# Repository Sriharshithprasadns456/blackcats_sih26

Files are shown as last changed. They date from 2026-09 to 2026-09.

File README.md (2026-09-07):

# BLACKCATS_SIH26
This Smart India Hackathon 2026 presentation by Team BLACKCATS details HI-CAS (Helmet-Integrated Conformal Antenna System).
# 🐈‍⬛ BLACKCATS — HI-CAS

### Helmet-Integrated Conformal Antenna System for Tactical Communications

> **ONE TEAM. ONE LINK. ZERO COMMUNICATION GAPS.**






---

## 📌 About the Project

**HI-CAS (Helmet-Integrated Conformal Antenna System)** is a compact, low-profile antenna architecture designed for **tactical communication in confined urban environments and Close-Quarter Battle (CQB) operations**.

The system replaces conventional protruding whip antennas with **helmet-integrated conformal antenna arrays**, reducing exposed hardware while maintaining reliable RF communication.

The proposed architecture uses **two independent single-band conformal antenna arrays**, supporting **UHF and L-band communication**, with a **diplexer** providing a single RF interface and **phase control** for improved signal coverage.

---

## 🎯 Problem Statement

### SIH 2026 — Problem Statement ID: 26185

**Helmet mounted conformal antenna for tactical communications in urban CQB environments.**

Traditional radio antennas create several challenges in confined environments:

* 📡 Protruding antennas can snag on surroundings.
* 🪖 Rigid antennas do not conform to helmet geometry.
* 📶 Helmet curvature and head proximity affect RF performance.
* 🔄 A compact platform must support multiple communication bands.
* ⚙️ Antenna performance can vary under realistic operating conditions.

---

## 💡 Our Solution

HI-CAS integrates the antenna directly with the helmet surface while maintaining a compact and modular architecture.

### Key Features

| Feature | Description |
| --- | --- |
| 🪖 **Conformal** | Follows the curvature of the helmet |
| 📡 **Dual-Band Architecture** | Separate optimized arrays for UHF and L-band |
| 📏 **Low Profile** | Minimizes exposed hardware and snag risk |
| 🔌 **Single RF Interface** | UHF and L-band are combined through a diplexer |
| 🎛️ **Phase Control** | Optimizes radiation coverage |
| 🔧 **Retrofittable** | Designed for compatibility with existing helmet systems |
| 🧩 **Modular** | Architecture can be adapted to different helmet/radio platforms |

---

## 🏗️ System Architecture

```text
                 ┌─────────────────────┐
                 │     HELMET SHELL    │
                 └──────────┬──────────┘
                            │
             ┌──────────────┴──────────────┐
             │                             │
     ┌───────▼────────┐           ┌────────▼───────┐
     │  UHF CONFORMAL │           │ L-BAND         │
     │     ARRAY      │           │ CONFORMAL ARRAY│
     └───────┬────────┘           └────────┬───────┘
             │                             │
             └──────────────┬──────────────┘
                            │
                      ┌─────▼─────┐
                      │  DIPLEXER │
                      └─────┬─────┘
                            │
                      ┌─────▼─────┐
                      │ PHASE     │
                      │ CONTROL   │
                      └─────┬─────┘
                            │
                      ┌─────▼─────┐
                      │ SINGLE RF │
                      │ INTERFACE │
                      └───────────┘
```

### Operating Bands

* **UHF:** 200–450 MHz
* **L-band:** 1.2–1.5 GHz

The architecture combines the two independently optimized antenna paths into a **single tactical RF interface**.

---

## 🔬 Engineering Approach

The project focuses on integrating existing RF technologies into a helmet-compatible platform and validating their performance under realistic operating conditions.

### Development Flow

```text
DESIGN
   ↓
SIMULATE
   ↓
PROTOTYPE
   ↓
BEND TEST
   ↓
TEMPERATURE TEST
   ↓
RF VALIDATION
   ↓
STRUCTURAL VALIDATION
```

The main engineering challenges include:

### 1. Helmet Curvature

Bending can alter electrical length and electromagnetic coupling.

**Parameters to evaluate:**

* Resonant frequency
* S11
* VSWR
* Bandwidth

### 2. Temperature

Environmental temperature variations can influence antenna materials and RF behaviour.

**Validation:**

* RF measurements before temperature cycling
* RF measurements after temperature cycling

### 3. Head Proximity

The operator's head changes the electromagnetic environment surrounding the antenna.

**Parameters:**

* Impedance
* Efficiency
* Radiation characteristics

### 4. Structural Integration

The antenna must integrate with the helmet without compromising its intended functionality or protection.

Structural/ballistic certification is **not claimed** by this project and would require dedicated validation.

---

## 🧪 Validation

The prototype will be evaluated through:

* Antenna simulation
* S-parameter measurements
* VSWR measurements
* Bandwidth characterization
* Curvature/bending tests
* Temperature testing
* Head-proximity testing
* Radiation-pattern evaluation
* Efficiency measurements
* Structural integration assessment

---

## 🚀 Expected Impact

### Operational

Reduced physical obstruction and improved operator mobility in confined environments.

### RF Performance

Independent band-optimized conformal arrays provide a flexible approach to multi-band tactical communication.

### User Safety

Reduced exposed antenna components can reduce potential snag points.

### Scalability

The modular UHF/L-band architecture can potentially be adapted to different helmet and radio platforms.

### Potential Applications

* NSG / ATS teams
* Specialized tactical units
* Helmet-based communication systems
* Other applications requiring compact integrated RF systems

All applications remain subject to appropriate technical validation, certification and procurement requirements.

---

## 🛠️ Technologies & Tools

### RF / Antenna

* Conformal antenna arrays
* UHF antenna design
* L-band antenna design
* Diplexer
* Phase-control network
* RF measurement and characterization

### Simulation & Design

The project can be developed and validated using electromagnetic simulation and RF design tools.

### Hardware

* Helmet-integrated antenna prototype
* RF interconnects
* Diplexer
* Phase-control circuitry
* Tactical-radio interface

---

## 📂 Repository Structure

```text
blackcats_sih26/
│
├── README.md
│
├── antenna-design/
│   ├── UHF/
│   └── L-band/
│
├── simulations/
│   ├── radiation-patterns/
│   ├── S11/
│   ├── VSWR/
│   └── bandwidth/
│
├── hardware/
│   ├── schematics/
│   ├── PCB/
│   └── prototype/
│
├── mechanical/
│   ├── helmet-CAD/
│   └── mounting/
│
├── results/
│   ├── measurements/
│   └── plots/
│
├── documentation/
│
└── LICENSE
```

---

## 👥 Team

### BLACKCATS

**Smart India Hackathon 2026**

**Team ID:** 007
**Problem Statement:** 26185
**Category:** Hardware
**Theme:** Robotics and Drones

---

## 📜 Project Status

🚧 **Prototype / Development Stage**

The project is currently focused on antenna design, simulation, prototype development and validation.

The core technologies required for the system exist; the primary engineering challenge is their **integration and validation under realistic operating conditions**.

---

## 📚 References

Project documentation and research material will be maintained in this repository.

**Official repository:**
https://github.com/Sriharshithprasadns456/blackcats_sih26

---

## ⚠️ Disclaimer

This project is a **research and engineering prototype** developed for Smart India Hackathon 2026.

Performance, structural integrity, ballistic protection and operational suitability must be independently validated before any real-world deployment.

---

<p align="center">

### 🐈‍⬛ BLACKCATS

**ONE TEAM. ONE LINK. ZERO COMMUNICATION GAPS.**

</p>

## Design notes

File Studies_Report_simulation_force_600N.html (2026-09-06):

- Header
- Report Properties
- Simulation Model 1
  - Study 1 - Static Stress
    - Study Properties
    - Study Setup
      - Settings
      - Materials
      - Contacts
      - Mesh
      - Load Case1
        - Constraints
        - Loads
        - Guided Results
          - Safety Factor
        - Results
          - Result Summary
          - Safety Factor
          - Stress
          - Displacement

Study Report

Analyzed File | helmet | Version | Autodesk Fusion (2704.1.53)
Creation Date | 2026-09-06, 05:58:10 | Author | HP

Report Properties

Report Properties
Title | Studies
Author | HP

Simulation Model 1

Study 1 - Static Stress

Study Properties

Study Properties
Study Type | Static Stress
Last Modification Date | 2026-09-06, 05:12:41

Study Setup

Settings
General

Contact Tolerance | 0.10 mm
Remove Rigid Body Modes | No
Mesh

Average Element Size (% of model size) - Solids | 10
Scale Mesh Size Per Part | No
Average Element Size (absolute value) | -
Element Order | Parabolic
Create Curved Mesh Elements | Yes
Max. Turn Angle on Curves (Deg.) | 60
Max. Adjacent Mesh Size Ratio | 1.5
Max. Aspect Ratio | 10
Minimum Element Size (% of average size) | 20
Adaptive Mesh Refinement

Number of Refinement Steps | 0
Results Convergence Tolerance (%) | 20
Portion of Elements to Refine (%) | 10
Results for Baseline Accuracy | von Mises Stress

Materials
Nylon 6/6(2)
Components

Component | Strength
Body3 | Yield Strength
Properties

Density | 1.420E-06 kg / mm^3
Young's Modulus | 2500.00 MPa
Poisson's Ratio | 0.34
Yield Strength | 69.00 MPa
Ultimate Tensile Strength | 231.00 MPa
Thermal Conductivity | 1.200E-04 W / (mm C)
Thermal Expansion Coefficient | 2.000E-05 / C
Specific Heat | 1090.00 J / (kg C)
Nylon 6/6(1)
Components

Component | Strength
Body5 | Yield Strength
Properties

Density | 2.202E-06 kg / mm^3
Young's Modulus | 3712.00 MPa
Poisson's Ratio | 0.17
Yield Strength | 138.00 MPa
Ultimate Tensile Strength | 69.00 MPa
Thermal Conductivity | 2.000E-04 W / (mm C)
Thermal Expansion Coefficient | 4.000E-05 / C
Specific Heat | 960.00 J / (kg C)
TPU(1)
Components

Component | Strength
Body7 | Yield Strength
Properties

Density | 2.240E-06 kg / mm^3
Young's Modulus | 1500.00 MPa
Poisson's Ratio | 0.40
Yield Strength | 19.00 MPa
Ultimate Tensile Strength | 19.00 MPa
Thermal Conductivity | 4.300E-04 W / (mm C)
Thermal Expansion Coefficient | 1.200E-04 / C
Specific Heat | 950.00 J / (kg C)
Nylon 6/6(3)
Components

Component | Strength
Body2 | Yield Strength
Properties

Density | 4.800E-06 kg / mm^3
Young's Modulus | 120000.00 MPa
Poisson's Ratio | 0.28
Yield Strength | 45.00 MPa
Ultimate Tensile Strength | 45.00 MPa
Thermal Conductivity | 0.004 W / (mm C)
Thermal Expansion Coefficient | 9.000E-06 / C
Specific Heat | 750.00 J / (kg C)
Nylon 6/6(4)
Components

Component | Strength
Body1 | Yield Strength
Body10 | Yield Strength
Body11 | Yield Strength
Body12 | Yield Strength
Body13 | Yield Strength
Body14 | Yield Strength
Body8 | Yield Strength
Body9 | Yield Strength
Properties

Density | 1.440E-06 kg / mm^3
Young's Modulus | 70300.00 MPa
Poisson's Ratio | 0.36
Yield Strength | 2920.00 MPa
Ultimate Tensile Strength | 3620.00 MPa
Thermal Conductivity | 4.000E-05 W / (mm C)
Thermal Expansion Coefficient | 1.000E-07 / C
Specific Heat | 1420.00 J / (kg C)
Copper
Components

Component | Strength
Body4 | Yield Strength
Body6 | Yield Strength
Properties

Density | 8.940E-06 kg / mm^3
Young's Modulus | 117500.00 MPa
Poisson's Ratio | 0.345
Yield Strength | 33.30 MPa
Ultimate Tensile Strength | 210.00 MPa
Thermal Conductivity | 0.401 W / (mm C)
Thermal Expansion Coefficient | 1.670E-05 / C
Specific Heat | 450.00 J / (kg C)

Contacts
Contact Type | Contact Set | Penetration Type | Bodies | Entities
Bonded

Bonded1 | Symmetric | [Body13||Body14] | [Face 1066||Face 1088]
Bonded2 | Symmetric | [Body12||Body14] | [Face 1045||Face 1088]
Bonded3 | Symmetric | [Body12||Body13] | [Face 1045||Face 1067]
Bonded4 | Symmetric | [Body11||Body12] | [Face 1024||Face 1046]
Bonded5 | Symmetric | [Body10||Body11] | [Face 1004||Face 1024]
Bonded6 | Symmetric | [Body10||Body12] | [Face 1003||Face 1046]
Bonded7 | Symmetric | [Body10||Body11] | [Face 1003||Face 1025]
Bonded8 | Symmetric | [Body9||Body12] | [Face 982||Face 1046]
Bonded9 | Symmetric | [Body9||Body11] | [Face 982||Face 1025]
Bonded10 | Symmetric | [Body9||Body10] | [Face 982||Face 1004]
Bonded11 | Symmetric | [Body8||Body9] | [Face 961||Face 983]
Bonded12 | Symmetric | [Body7||Body14] | [Face 945||Face 1089]
Bonded13 | Symmetric | [Body7||Body14] | [Face 944||Face 1092]
Bonded14 | Symmetric | [Body7||Body14] | [Face 943||Face 1091]
Bonded15 | Symmetric | [Body7||Body14] | [Face 942||Face 1090]
Bonded16 | Symmetric | [Body6||Body7] | [Face 929||Face 946]
Bonded17 | Symmetric | [Body6||Body12] | [Face 925||Face 1049]
Bonded18 | Symmetric | [Body5||Body13] | [Face 911||Face 1067]
Bonded19 | Symmetric | [Body5||Body7] | [Face 911||Face 946]
Bonded20 | Symmetric | [Body5||Body6] | [Face 911||Face 928]
Bonded21 | Symmetric | [Body5||Body12] | [Face 909||Face 1047]
Bonded22 | Symmetric | [Body5||Body9] | [Face 909||Face 984]
Bonded23 | Symmetric | [Body5||Body12] | [Face 908||Face 1050]
Bonded24 | Symmetric | [Body5||Body9] | [Face 908||Face 987]
Bonded25 | Symmetric | [Body5||Body12] | [Face 907||Face 1049]
Bonded26 | Symmetric | [Body5||Body9] | [Face 907||Face 986]
Bonded27 | Symmetric | [Body5||Body12] | [Face 906||Face 1048]
Bonded28 | Symmetric | [Body5||Body9] | [Face 906||Face 985]
Bonded29 | Symmetric | [Body4||Body5] | [Face 893||Face 910]
Bonded30 | Symmetric | [Body4||Body9] | [Face 891||Face 984]
Bonded31 | Symmetric | [Body4||Body9] | [Face 889||Face 986]
Bonded32 | Symmetric | [Body3||Body5] | [Face 875||Face 910]
Bonded33 | Symmetric | [Body3||Body4] | [Face 875||Face 892]
Bonded34 | Symmetric | [Body3||Body4] | [Face 874||Face 893]
Bonded35 | Symmetric | [Body3||Body12] | [Face 871||Face 1049]
Bonded36 | Symmetric | [Body2||Body10] | [Face 857||Face 1004]
Bonded37 | Symmetric | [Body2||Body5] | [Face 857||Face 910]
Bonded38 | Symmetric | [Body2||Body4] | [Face 857||Face 892]
Bonded39 | Symmetric | [Body2||Body3] | [Face 857||Face 874]
Bonded40 | Symmetric | [Body2||Body9] | [Face 855||Face 984]
Bonded41 | Symmetric | [Body2||Body9] | [Face 854||Face 987]
Bonded42 | Symmetric | [Body2||Body9] | [Face 853||Face 986]
Bonded43 | Symmetric | [Body2||Body9] | [Face 852||Face 985]
Bonded44 | Symmetric | [Body1||Body9] | [Face 839||Face 983]
Bonded45 | Symmetric | [Body1||Body2] | [Face 839||Face 856]
Bonded46 | Symmetric | [Body1||Body8] | [Face 837||Face 963]
Bonded47 | Symmetric | [Body1||Body8] | [Face 836||Face 966]
Bonded48 | Symmetric | [Body1||Body8] | [Face 835||Face 965]
Bonded49 | Symmetric | [Body1||Body8] | [Face 834||Face 964]

Mesh
Type | Solids
Nodes | 946653
Elements | 469752

Load Case1

Constraints
Fixed1

Type | Fixed
Ux | Fixed
Uy | Fixed
Uz | Fixed

Loads
Force2

Type | Force
Magnitude | 600.00 N
X Value | 0.00 N
Y Value | -600.00 N
Z Value | 0.00 N
X Angle | 0.0 deg
Y Angle | 0.0 deg
Z Angle | 0.0 deg
Force Per Entity | No
Force3

Type | Force
Magnitude | 600.00 N
X Value | -147.51 N
Y Value | -581.585 N
Z Value | 0.00 N
Force Per Entity | No

Load Case1 - Guided Results

Safety Factor

With the analysis criteria in this study setup, the design is expected to bend permanently or break.

Next Steps

Below Safety Factor Target

Validate your study setup

Check the loads are not set too high

Check the mesh refinement and consider increasing it in areas of high stress

Confirm your Safety Factor requirement

If the Displacement result shows high displacement, consider running a Nonlinear study to gain more insight

Check other results

Examine the Below target Result visualization to see where the weakest areas are

Check the stress result to see if, and where, the material might yield

Check the displacement result to see how far from its original alignment the model has moved

Look at other results, such as reaction forces to check your study set up, or strain to check your material performance

Strengthen weak areas

Add more material to weak areas

Select a material with a higher yield strength

Stiffen the design

Modify the shape with a Generative Design study

Generate alternative designs

Add more material to weak areas

Select a material with a higher yield strength

Stiffen the design

Modify the shape with a Generative Design study

Above Safety Factor Limit

Validate your study setup

Check the loads are not set too high

Check the mesh refinement and consider increasing it in areas of high stress

Confirm your Safety Factor requirement

If the Displacement result shows high displacement, consider running a Nonlinear study to gain more insight

Check other results

Examine the Below target Result visualization to see where the weakest areas are

Check the stress result to see if, and where, the material might yield

Check the displacement result to see how far from its original alignment the model has moved

Look at other results, such as reaction forces to check your study set up, or strain to check your material performance

Lightweight the design

Set a Safety Factor upper limit to find where material can be removed

Remove material from areas that exceed the Safety Factor upper limit

Generate alternative designs

In the Generative Design workspace, create design modifications

Remove unnecessary material using a Shape Optimization study

Load Case1 - Results

Result Summary
Result type | Sub-result | Minimum | Maximum
Safety Factor

Safety Factor | 4.719 | 539,427.75
Stress

Von Mises | 5.364E-04 MPa | 7.057 MPa
1st Principal | −5.203 MPa | 13.805 MPa
3rd Principal | −9.764 MPa | 6.687 MPa
Normal XX | −5.779 MPa | 6.831 MPa
Normal YY | −8.113 MPa | 13.107 MPa
Normal ZZ | −6.006 MPa | 7.381 MPa
Shear XY | −3.103 MPa | 2.256 MPa
Shear YZ | −2.064 MPa | 1.747 MPa
Shear XZ | −0.697 MPa | 0.551 MPa
Displacement

Total | 0 mm | 0.001 mm
X | −1.387E-04 mm | 1.401E-04 mm
Y | −0.001 mm | 1.30E-06 mm
Z | −1.533E-04 mm | 1.546E-04 mm
Reaction Force

Total | 0 N | 4.675 N
X | −0.336 N | 0.34 N
Y | −0.169 N | 4.664 N
Z | −0.481 N | 0.431 N
Strain

Equivalent | 1.033E-07 | 1.574E-04
1st Principal | −4.951E-06 | 9.892E-05
3rd Principal | −1.701E-04 | −1.032E-07
Normal XX | −2.312E-05 | 2.106E-05
Normal YY | −9.599E-05 | 6.982E-05
Normal ZZ | −3.751E-05 | 2.947E-05
Shear XY | −1.11E-04 | 1.102E-04
Shear YZ | −1.28E-04 | 1.275E-04
Shear XZ | −2.695E-05 | 2.462E-05
Contact Pressure

Total | 0 MPa | 13.77 MPa
X | −3.413 MPa | 3.608 MPa
Y | −7.976 MPa | 12.918 MPa
Z | −4.585 MPa | 3.954 MPa
Contact Force

Total | 0 N | 39.719 N
X | −13.717 N | 14.877 N
Y | −32.105 N | 39.704 N
Z | −13.487 N | 13.505 N

Safety Factor

Safety Factor

Stress

1st Principal

$$ImageCompatibilityInfo$

3rd Principal

$$ImageCompatibilityInfo$

Displacement

Total

$$ImageCompatibilityInfo$

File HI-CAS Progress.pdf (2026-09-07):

SMART INDIA HACKATHON 2026

# PROGRESS REPORT

## Hi-CAS: Helmet-Integrated Conformal Antenna System

Field | Details
Problem Statement ID | 26185
Problem Statement Title | Helmet mounted conformal antenna for tactical communications in urban CQB environments
Theme | Robotics and Drones
PS Category | Hardware
Team ID | 007
Team Name | BLACKCATS
Team Motto | One Team. One Link. Zero Communication Gaps.
Report Date | 6 September 2026

Status: Concept design, RF stack-up, mechanical CAD and preliminary structural simulation complete.

## 1. Executive Summary

Team BLACKCATS is developing Hi-CAS (Helmet-Integrated Conformal Antenna System), a low-profile, helmet-conformal dual-band antenna solution that replaces the traditional external whip antenna used in tactical radios. This report summarizes the work completed to date against Problem Statement 26185: concept definition, RF architecture and layer stack-up design, patch antenna sizing and substrate selection, helmet CAD modelling in Fusion 360, and a first-pass structural (static stress) simulation of the antenna-integrated helmet shell under a 600 N load.

At this stage, the design and its RF/mechanical rationale are complete and documented; the structural simulation shows a comfortable safety margin (minimum safety factor 4.72) and negligible deformation, indicating that the added antenna layers do not compromise the mechanical integrity of the underlying helmet shell in this simplified static model. The full layered helmet CAD model (all stack-up layers at their specified dimensions) has also been successfully constructed and simulated in Fusion 360. On the RF side, construction of the L-band antenna has begun: the team started with a planar (flat) patch element before attempting a curved/bent version, and CST simulation — after initially returning a flat, resonance-free S-parameter line — now shows clear resonant dips, confirming the element is functioning and ready for dimensional tuning. Detailed EM simulation of the conformal/curved arrays, physical prototyping, and ballistic-grade validation remain as next steps.

## 2. Problem Statement

Traditional external whip antennas mounted on tactical helmets create a physical and RF trade-off in confined, closequarter-battle (CQB) urban environments:

- Exposed hardware: external whip antennas protrude and snag on surroundings, interfering with operator movement.
- Non-conformal form: rigid antennas do not follow helmet geometry, causing fit and integration issues.
- RF performance variation: helmet curvature, proximity to human tissue, and the surrounding environment affect antenna impedance and radiation behaviour.
- Multi-band challenge: a single compact platform must reliably support and operate across both UHF and L-band tactical frequencies.

## 3. Proposed Solution — Hi-CAS

Hi-CAS integrates two independent, low-profile conformal antenna arrays onto the helmet surface, connected through a diplexer so that both bands share a single RF interface to the radio:

- UHF array (200–450 MHz): a conformal array optimized for the UHF tactical band, positioned on the rear/crown region of the helmet.
- L-band array (1.2–1.5 GHz): a second conformal array optimized for the L-band, positioned separately from the UHF array to minimize mutual coupling.
- 3-port diplexer: combines/separates the UHF and L-band signals into a single RF interface to the transceiver.
- Phase-control network: a phase shifter optimizes signal coverage for reliable, ~360° azimuth tactical communication.

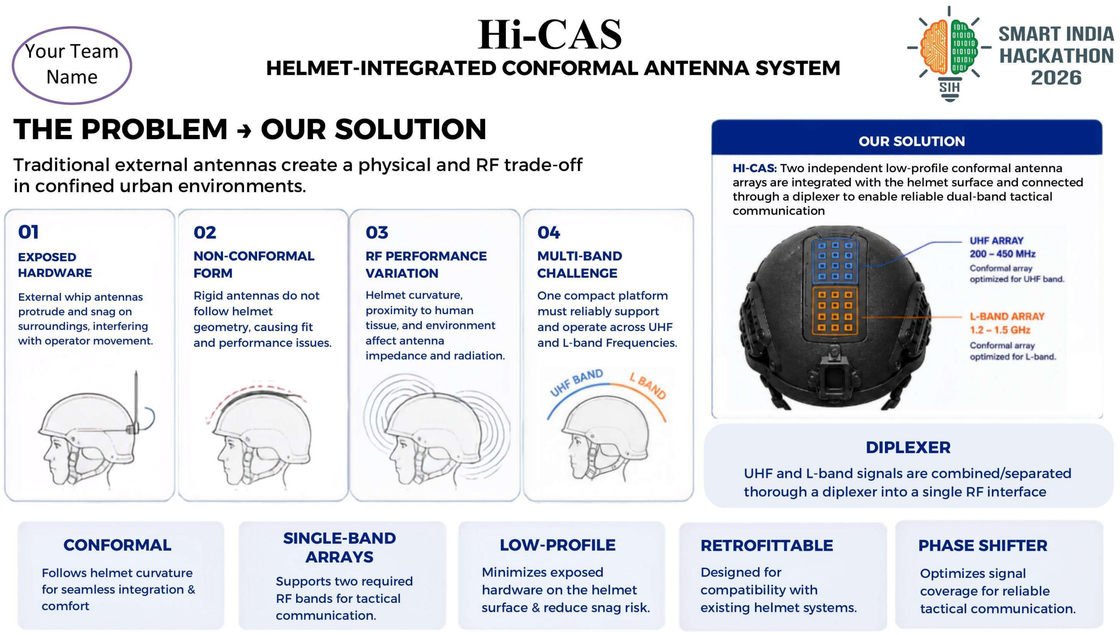
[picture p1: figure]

Figure 1: Hi-CAS solution overview — from exposed external antenna to an integrated, helmet-conformal dual-band system (Team BLACKCATS, SIH 2026).

Design pillars carried through the concept:

- Conformal — follows helmet curvature for seamless integration and comfort.
- Single-band arrays — two purpose-built arrays instead of one compromised multi-band element.
- Low-profile — minimizes exposed hardware on the helmet surface and reduces snag risk.
- Retrofittable — designed for compatibility with existing helmet systems.
- Phase-shifted feed — optimizes coverage for reliable tactical communication.

## 4. RF and Communications Architecture

### 4.1 End-to-end communication stack

The antenna is the physical layer of a complete tactical communications stack. The system architecture defined so far is:

- Helmet Antenna (Hi-CAS conformal arrays)
- RF Transceiver / Radio
- PHY Layer
- Data Link Layer
- Networking Layer
- Transport Layer
- Application Layer — tactical COMSEC / TRANSEC implementation

### 4.2 Antenna design and validation workflow

The antenna element itself is being developed and validated in stages, moving from a simple flat patch to a full conformal, multi-element array:

- Design a single microstrip patch element.
- Check S11 / VSWR.
- Check the 3D radiation pattern.
- Rotate the antenna and evaluate different orientations.
- Understand how the radiation pattern changes with orientation.
- Add helmet curvature to the model (transition from flat to conformal).

- Develop multiple conformal elements.
- Combine elements into arrays.
- Optimize the combined arrays for close to 360° azimuth coverage.

### 4.3 Patch antenna element and substrate

The radiating element follows the classical microstrip patch configuration — a copper patch on a grounded dielectric substrate, fed by a microstrip feed line.

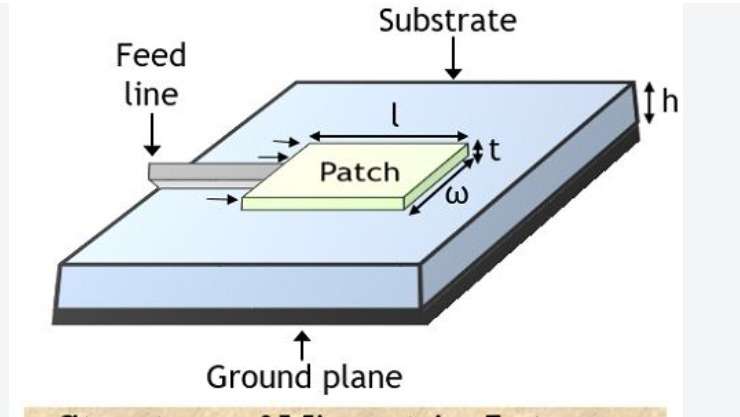
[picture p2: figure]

Figure 2: Generic microstrip patch antenna geometry — patch, feed line, dielectric substrate and ground plane.

RT/duroid 5880 was selected as the working substrate for initial sizing and simulation because of its low loss tangent and stable dielectric constant, which suit conformal antenna applications:

Parameter | RT/duroid 5880
Substrate | RT/duroid 5880
Substrate thickness | 0.127 mm
Copper thickness | 35 µm (~1 oz/ft²)
Antenna conductor | Copper
Ground | Copper

### 4.4 Helmet sizing constraints on antenna footprint

Antenna footprint was cross-checked against the Ministry of Home Affairs Bullet Resistant Helmet specification, which defines head circumference and sagittal-arc ranges for three helmet sizes. The sagittal arc — the curved distance over the top of the head from the glabella to the base of the occiput — is the most relevant dimension for conformal antenna placement.

Size | Head circumference | Sagittal arc
Small | 48–52 cm | 30–35 cm
Medium | >52–57 cm | >35–39 cm
Large | >57–64 cm | >39–44 cm

Note: the sagittal arc describes the helmet/head curvature, not the available flat antenna footprint. For a medium helmet, the working assumption for the central curved patch region is approximately 120–160 mm long × 70–100 mm wide, with exact dimensions to be finalized through HFSS/CST optimization for the chosen UHF and L-band frequencies. As a crossreference, commercial Indian tactical helmets (e.g. MKU KAVRO DOMA 360) specify head circumferences of 500–530 mm, 530–570 mm and 570–600 mm for small, medium and large respectively.

### 4.5 Conformal layer stack-up

Two candidate stack-ups have been worked through for the flexible antenna assembly bonded to the helmet shell. The first is an early dimensional draft (each layer cut progressively larger than the one below it, from radiator outward, to allow for lamination tolerance):

Layer | Starting length | Starting width | Thickness
Radiating copper | 150 mm | 90 mm | 35 µm
Flexible substrate | 160 mm | 100 mm | 0.127 mm / 0.05 mm
Ground copper | 155 mm | 95 mm | 35 µm
Kapton isolation | 160 mm | 100 mm | 50 µm
Ferrite absorber | 160 mm | 100 mm | 100–200 µm
Protective outer film | 165 mm | 105 mm | application-dependent

This was consolidated into the current working stack-up (outside to inside), which is the version carried into the helmet integration model:

Order (outside → inside) | Layer | Thickness
1 | Silicone rubber protective layer | —
2 | Copper radiator | | 0.035 mm
3 | RT/duroid 5880 (dielectric) | | 0.127 mm
4 | Copper ground | | 0.035 mm
5 | Kapton isolation | | 0.05 mm
6 | Ferrite absorber (if retained) | | 0.20 mm
7 | Helmet shell | | 15 mm

A key design rule carried through both iterations: the ballistic helmet shell remains structurally uninterrupted. The full functional stack, from outside to head, is: thin protective coating → flexible antenna (RF radiating layer) → flexible dielectric → RF ground/shield → electrical isolation → ballistic helmet shell (bullet protection, uninterrupted) → impactabsorbing liner → head. No RF layer penetrates or replaces load-bearing ballistic material.

### 4.6 L-band Antenna — First EM Simulation Results

Construction of the L-band antenna has begun. Following the staged workflow in Section 4.2, the team deliberately started with a flat (planar) patch antenna before attempting the curved/bent conformal version, so that the basic resonance behaviour of the element could be verified on simple, well-understood geometry first.

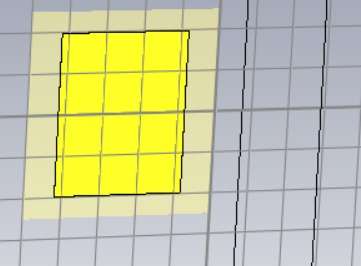
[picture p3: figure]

Figure 5: Planar L-band patch element modelled on the CST mesh grid — the starting geometry before curvature/bending is introduced.

The first simulation attempt on this planar patch returned a flat S1,1 line with no visible resonance, indicating an issue with the initial port/feed or dimension setup. After revisiting the model, a re-run produced a proper S-parameter response with multiple resonance dips across the swept band:

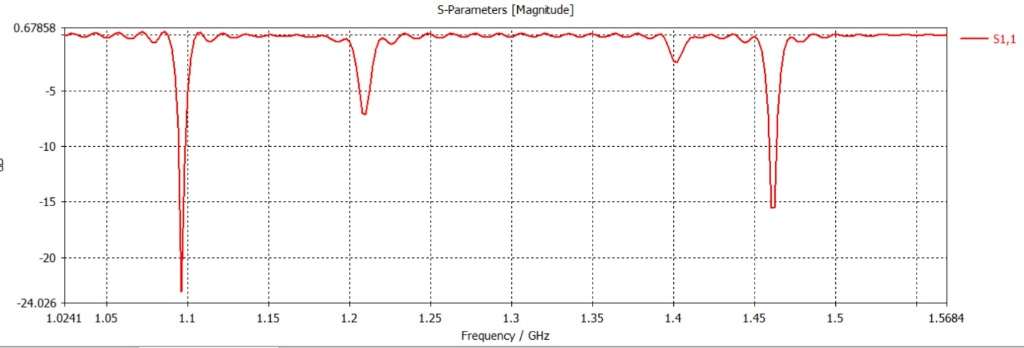
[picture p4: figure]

Figure 6: S1,1 magnitude vs. frequency for the planar L-band patch after correction — resonances near 1.10 GHz (−24.0 dB), 1.21 GHz (−7.1 dB), 1.40 GHz (−3.0 dB) and 1.46 GHz (−15.3 dB).

This confirms the patch is resonating and that the simulation setup (port, mesh, boundary conditions) is now functioning correctly. The strongest, cleanest dip at present falls just below the intended L-band (near 1.10 GHz), with a secondary, shallower dip at 1.46 GHz inside the 1.2–1.5 GHz target band. The next iteration will retune the patch length/width and feed position to consolidate this into a single, deep resonance centred inside the target L-band, before repeating the process on the curved/conformal version of the element.

## 5. Mechanical Design (CAD)

The helmet shell and the conformal antenna assembly were modelled together in Autodesk Fusion 360 as a multibody assembly and exported as a STEP AP214 file (Basic_helmet_element_design.step) for cross-platform CAD exchange and downstream simulation.

- The model is a dome-shaped ballistic helmet shell with a curved patch region on the crown representing the conformal antenna patch/array footprint.
- The assembly is decomposed into 14 solid bodies, matching the distinct material layers of the stack-up (helmet shell, liner, dielectric substrate, copper radiator, copper ground, protective/isolation layers).
- This body-per-layer approach allows each layer to be assigned its own material properties for structural simulation, and keeps the RF layer stack traceable back to the CAD model.
- The basic helmet design was successfully built and simulated in Fusion 360 with all stack-up layers present at their specified dimensions (Section 4.5), confirming the layered geometry is structurally sound and simulationready before EM co-simulation is attempted.

## 6. Structural Simulation — Static Stress Study (600 N)

A first-pass static structural simulation was run on the assembled CAD model in Fusion 360 to check whether bonding the thin antenna layers onto the helmet shell introduces any structural weakness, and to establish a baseline load-response before ballistic-specific testing.

### 6.1 Study setup

Setting | Value
Study type | Static Stress
Analyzed file | helmet (Fusion 360, v2704.1.53)
Mesh type | Solids, parabolic elements, curved mesh enabled
Average element size | 10% of model size
Nodes / Elements | 946,653 nodes / 469,752 elements
Constraint | Fixed support at the helmet rim (all translations fixed)
Applied load | Two 600 N forces on the crown/antenna patch region (representing an impact-type load case), oriented predominantly downward
Results basis | Baseline accuracy, von Mises stress criterion

### 6.2 Materials assigned per layer

Body / layer | Material | Yield strength | Young's modulus
Body1, 8–14 (shell/structure) | Nylon 6/6 (variant 4) | 2920.00 MPa* | 70,300 MPa
Body2 (shell layer) | Nylon 6/6 (variant 3) | 45.00 MPa | 120,000 MPa
Body3 (liner) | Nylon 6/6 (variant 2) | 69.00 MPa | 2,500 MPa
Body4, 6 (radiator / ground) | Copper | 33.30 MPa | 117,500 MPa
Body5 (dielectric) | Nylon 6/6 (variant 1) | 138.00 MPa | 3,712 MPa
Body7 (protective layer) | TPU | 19.00 MPa | 1,500 MPa

*As exported from the material library for this body; to be re-checked against manufacturer datasheets before the next simulation pass, since it is high relative to typical Nylon 6/6 yield values.

### 6.3 Load and boundary condition

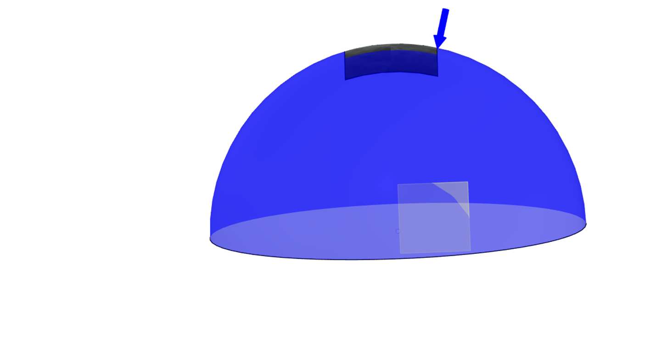
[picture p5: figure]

Figure 3: Load case — 600 N applied on the crown/antenna-patch region, with the helmet rim fixed.

### 6.4 Key results

Result | Minimum | Maximum
Safety factor | 4.72 | > 500,000 (capped)
Von Mises stress | ~0 MPa | 7.06 MPa
1st principal stress | −5.20 MPa | 13.81 MPa
3rd principal stress | −9.76 MPa | 6.69 MPa
Total displacement | 0 mm | 0.001 mm
Total reaction force | 0 N | 4.68 N
Equivalent strain | 1.03×10⁻⁷ | 1.57×10⁻⁴
Contact pressure | 0 MPa | 13.77 MPa

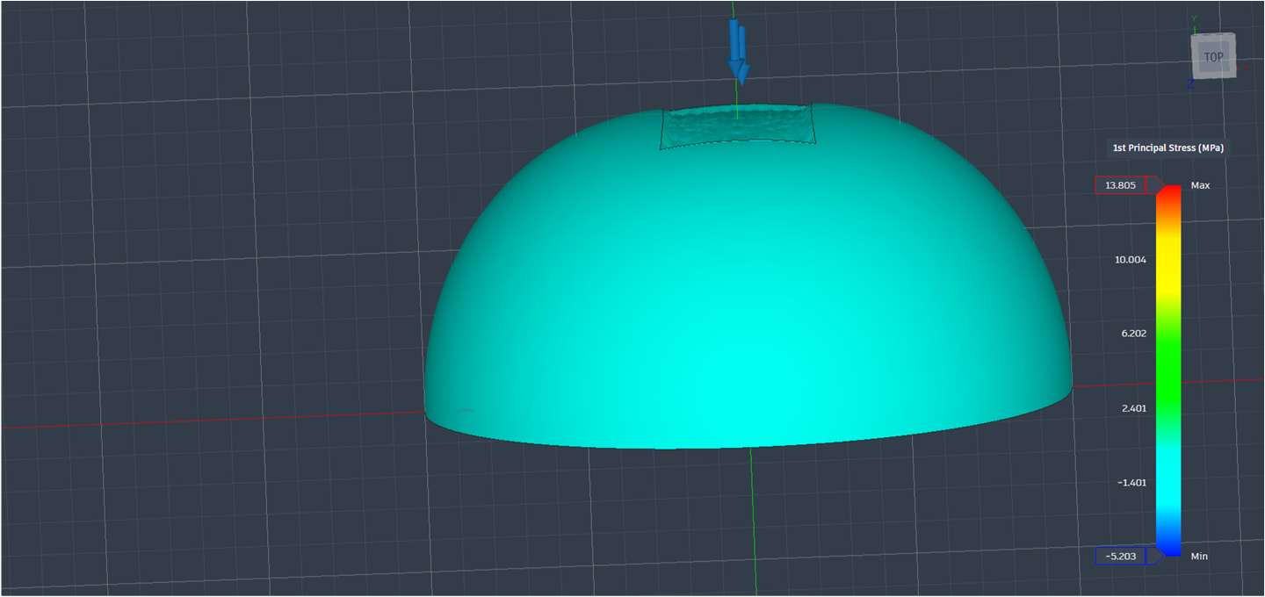
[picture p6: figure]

Figure 4: 1st principal stress distribution across the helmet shell under the 600 N load case (max 13.81 MPa, localized at the antenna patch region).

Interpretation: the minimum safety factor of 4.72 is well above 1.0, indicating that, in this simplified static model, none of the layers — including the copper radiator/ground and dielectric — is predicted to yield under the applied 600 N load. Displacement is negligible (≤ 0.001 mm), and peak stresses remain concentrated at the antenna patch region and well below the yield strengths of the assigned materials. This is a preliminary structural sanity check, not a certified ballistic test: it confirms that bonding the thin (sub-millimetre) antenna stack onto the shell does not introduce an obvious structural weak point, but it does not replace dedicated ballistic impact testing.

## 7. Feasibility and Engineering Challenges

Core antenna and helmet technologies already exist individually; the innovation and remaining risk lie in integrating them and validating performance under realistic conditions. Four challenge areas have been identified, each with a defined measurement approach:

Challenge | Description | How it will be measured
Curvature | Bending the antenna to follow the helmet surface alters its electrical length and EM coupling. | Resonant frequency, S11, VSWR, bandwidth (flat vs. conformal).
Temperature | Environmental temperature variation affects material and antenna behaviour. | RF performance before and after temperature cycling.
Head proximity | The operator's head changes the EM environment around the antenna. | Impedance, efficiency, and radiation- pattern characteristics with/without a head phantom.
Structural integration | The antenna must not compromise helmet functionality or ballistic protection. | Integration compatibility and structural/ballistic checks (no certification claimed at this stage).

### 7.1 Mitigation and validation sequence

The team is following a seven-step sequence to move from concept to a validated prototype:

- 1. Design
- 2. Simulate
- 3. Prototype
- 4. Bend test
- 5. Temperature test
- 6. RF validation
- 7. Structural validation

## 8. Progress Summary — What Has Been Done So Far

Area | Status | Output produced
Problem framing & solution
concept | Complete | Hi-CAS dual-band conformal architecture defined
| | (UHF + L-band arrays, diplexer, phase control).
Communications architecture | Complete (concept) | Full stack from antenna to application layer defined;
| | per-band frequency ranges fixed (UHF 200–450 MHz,
| | L-band 1.2–1.5 GHz).

Antenna element design

workflow | In progress | 9-step validation workflow defined; L-band planar
| | patch built and simulated in CST with resonance
| | confirmed (Section 4.6).
Substrate & material selection | Complete (initial) | RT/duroid 5880 dielectric, copper radiator/ground,
| | Kapton isolation, ferrite absorber, silicone protective
| | layer.
Layer stack-up dimensioning | Complete (initial),
| consolidated | Two iterations of the stack-up produced and reconciled
| | into one working stack.
Helmet sizing cross-check | Complete | Antenna footprint checked against MHA helmet-size
| | spec and a commercial reference helmet.

Mechanical CAD (helmet +

antenna layers) | Complete (v1) | 14-body Fusion 360 assembly with all stack-up layers
| | built to specified dimensions and successfully
| | simulated; exported as STEP
| | (Basic_helmet_element_design.step).
Structural simulation | Complete (v1, static,
| 600 N) | Static stress study: min. safety factor 4.72, max.
| | displacement 0.001 mm, max. von Mises stress 7.06
| | MPa.
Electromagnetic simulation (S11/VSWR, pattern, gain) | Started (L-band,
| planar) | Planar L-band patch simulated in CST Studio Suite;
| | resonance behaviour confirmed, dimensions being
| | tuned to centre on target band.
Physical prototyping &
bend/temperature testing | Not started | Planned after EM simulation is complete.

## 9. Impact and Potential Applications

Impact area | Benefit
Operational | Reduced physical obstruction and improved operator mobility.
RF performance | Independent, band-optimized arrays combined via a diplexer.
User safety | Fewer exposed antenna parts, reducing snag and injury risk.
Scalability | Modular UHF/L-band architecture for broad helmet and radio compatibility.

Potential end users: NSG / ATS teams and other specialized tactical units, and other helmet-based communication systems, subject to further validation and procurement processes.

## 10. Next Steps

- Run full electromagnetic simulation of the single patch and the combined conformal arrays in CST Studio Suite (S11/VSWR, 3D radiation pattern, gain, RF isolation between UHF and L-band arrays).
- Finalize the exact patch and array dimensions for the chosen UHF and L-band frequencies, replacing the current ~120–160 mm × 70–100 mm working estimate.
- Re-verify assigned material properties (especially the high yield-strength value flagged in Section 6.2) against manufacturer datasheets.
- Fabricate a flexible-PCB prototype of the antenna stack-up and bond it to a test helmet shell section.

- Execute the bend test, temperature-cycling test, RF validation, and structural validation stages of the mitigation sequence.
- Re-run the structural simulation with prototype-derived material data and, where possible, a more representative (dynamic/impact) load case.

— End of report —

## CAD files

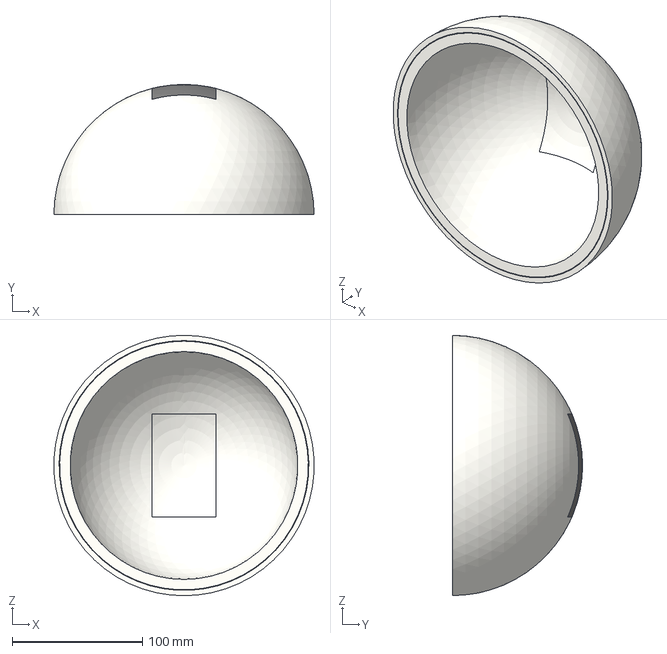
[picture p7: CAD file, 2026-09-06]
Basic helmet element design.step
199.7 x 100.0 x 200.0 mm
